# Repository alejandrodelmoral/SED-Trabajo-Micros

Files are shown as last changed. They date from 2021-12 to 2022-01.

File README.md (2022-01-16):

# Casa domótica 🏠

_Este proyecto se ha realizado para la asignatura de cuarto curso **Sistemas Electrónicos Digitales** impartida en el Grado en Ingeniería Electrónica Industrial y Automática, curso 2021/22._

**Escuela Técnica Superior de Ingeniería y Diseño Industrial**  
**Universidad Politécnica de Madrid**

## Miembros ✒️
* **Alejandro del Moral** - [alejandrodelmoral](https://github.com/alejandrodelmoral)
* **Jacob Sánchez** - [jacobsanchezmoreira](https://github.com/jacobsanchezmoreira)
* **Wei Zheng** - [weizheng13](https://github.com/weizheng13)

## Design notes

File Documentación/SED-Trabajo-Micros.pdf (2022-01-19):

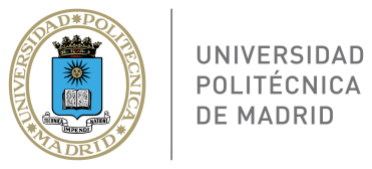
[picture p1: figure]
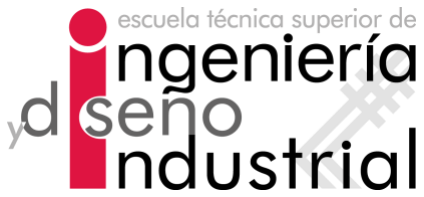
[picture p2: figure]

Alejandro del Moral Lapresta | 54753
Jacob Sánchez Moreira | 54863
Wei Zheng | 54911

## SISTEMAS ELECTRÓNICOS DIGITALES

## Universidad Politécnica de Madrid

Escuela Técnica Superior de Ingeniería y Diseño Industrial

Grado en Ingeniería Electrónica Industrial y Automática

# Casa domótica

Grupo: | Profesor:
A404 | Pedro Luis Castedo Cepeda

Madrid, enero de 2022

Sistemas Electrónicos Digitales | Casa domótica

### ÍNDICE DE CONTENIDOS

### ÍNDICE DE FIGURAS

### 1 INTRODUCCIÓN

En este proyecto se construirá y programará una casa domótica utilizando la placa de desarrollo STM32F407G-DISC1. Utilizando la tecnología se podrán realizar funciones para aumentar el grado de comodidad de las personas.

La casa constará de un control manual y un control por Bluetooth de la iluminación, temperatura, alarma y apertura de la puerta de la casa.

### 2 REALIZACIÓN DEL PROYECTO

### 2.1 COMPONENTES UTILIZADOS

a) Placa de desarrollo STM32F407G-DISC1
La placa utilizada posee un procesador Cortex-M4 de 32 bits RISC, de arquitectura Harvard con pipeline de 3 estados (Fech, decode y execute), lo que permite una ejecución eficiente del programa.

La documentación de la placa es muy extensa por lo que aquí se señalarán algunas de las características que han sido utilizadas para la realización de este trabajo.

- Frecuencia de reloj de hasta 168 MHz.
- Memoria Flash de 1 Mbyte.
- 3 conversores A/D de 12 bits.
- 2 conversores D/A de 12 bits.
- 12 temporizadores de 16 bits.
- 2 temporizadores de 32 bits.
- Hasta 140 puertos I/O con capacidad de interrupción.
- Comunicación I2C, USART, UART y CAN.

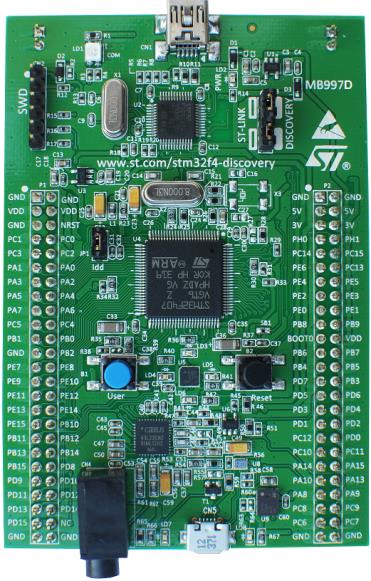
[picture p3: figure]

FIGURA 1. Placa STM32F407G b) Implementación del servomotor Datan S1213
De la hoja de características del fabricante podemos sacar los siguientes datos:
- Voltaje: 4,8 V
- Velocidad: 0,21 s / 60º
- Par: 6,5 kg ⋅ cm
- Peso: 46 g

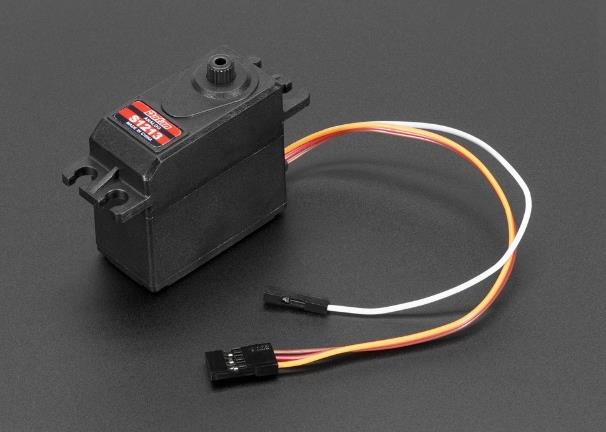
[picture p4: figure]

FIGURA 2. Servomotor Datan S1213

c) Implementación del módulo Bluetooth HC-06
Se ha decidido implementar una aplicación Bluetooth para poder elegir la función que se quiera ejecutar en la casa desde un dispositivo móvil.
- Protocolo Bluetooth: protocolo estándar Bluetooth V2.0
- Potencia: Class2 (+6 dBm)
- Banda: 2,40 HGz − 2,48 GHz, ISM Band
- Protocolo USB: USB v1.1/2.0
- Voltaje operativo: de +3,3 V a 6 V
- Rango de temperatura: de −20℃ a +55℃
- Intensidad operativa: 40 mA

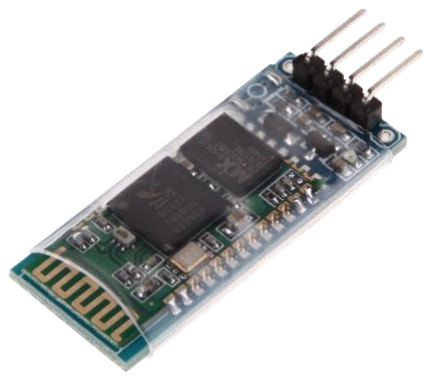
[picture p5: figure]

FIGURA 3. Módulo Bluetooth HC-06

d) Implementación del sensor de ultrasonidos HC-SR04
El sensor de ultrasonidos es un dispositivo electrónico usado para la detección de objetos y medición de distancias. Su funcionamiento se basa en el envío de ondas de alta frecuencia (40 kHz) que chocan con un objeto y se reflejan volviendo de nuevo al sensor.

En la hoja de especificaciones del fabricante nos encontramos con información detallada para el conexionado y parámetros característicos. Los datos más relevantes son los siguientes:

- Voltaje operativo: 5 V
- Intensidad operativa: 15 mA
- Frecuencia de trabajo máxima: 40 Hz
- Distancia de detección mínima: 2 cm
- Distancia de detección máxima: 400 cm
- Ángulo máximo de medición: 30º
- Pulso de señal de entrada (Trigger): 10 μs
- Pulso de señal de salida (Echo): Proporcional a la distancia, Máx de 23,3 ms

El envío de la señal ultrasónica es producido por el pin Trigger al ser excitado por un pulso de 10 μs. Es suficiente con la señal de 3,3 V que provee la placa para activarse.

La recepción de la señal es captada por el pin Echo, produciendo un pulso de duración idéntica al tiempo transcurrido entre el envío y la recepción de esa onda. Debido a que el voltaje de trabajo del sensor (5 V) y de la placa (3,3 V) son distintos, es necesario adaptar la amplitud de la señal a un rango que pueda leer la placa. Para ello se ha optado por implementar un divisor de tensión con dos resistencias (1 kΩ y 2 kΩ) para ajustar los valores de 5 a 3,3 V.

La distancia es fácilmente calculable sabiendo que la onda viaja a la velocidad del sonido, 340 m/s, y conociendo el ancho de pulso que nos proporciona el sensor. Sin embargo, el tiempo que nos proporciona el sensor es el transcurrido entre la ida y la vuelta, por lo que habría que dividir ese tiempo entre 2.

Distancia =

TiempoIda−Vuelta
2
- Vsonido

Para la obtención del tiempo a través de la lectura de la señal de salida del pin Echo se ha optado por el uso de un temporizador en modo de captura de señal. Este modo permite obtener el tiempo en el que se ha producido un flanco, ya sea de subida o de bajada.

La detección de los flancos es capturada con una interrupción del temporizador.

Sabiendo que se va a producir un pulso de duración determinada, es suficiente con detectar un flanco de subida, cambiar el modo de detección a flancos de bajada, y detectar un flanco de bajada. Con esa diferencia de tiempos se puede proceder al cálculo de la distancia.

No es un sensor muy preciso, se obtienen buenas aproximaciones de la distancia con errores de ± 0.5 cm. Suficiente para el propósito de nuestro trabajo.

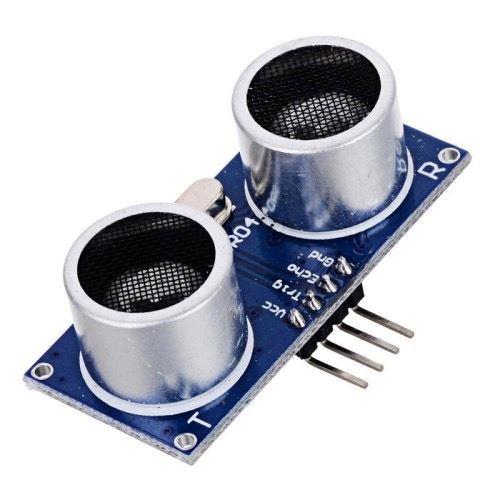
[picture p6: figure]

FIGURA 4. Sensor de ultrasonidos HC-SR04

e) Implementación del sensor LDR
Se trata de un resistor que varía su valor de resistencia eléctrica dependiendo de la cantidad de luz que incide sobre él.

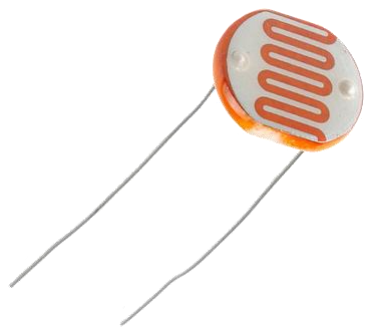
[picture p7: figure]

FIGURA 5. Sensor LDR

f) Implementación del zumbador pasivo
Se usa para generar un “chirrido” electromagnético utilizado para generar señales de sonido de diferentes frecuencias.

El principio de funcionamiento del zumbador pasivo es utilizar un pulso PWM que hace vibrar el aire para generar un sonido. Por ejemplo, enviando un pulso de 523 Hz, genera una nota Do, con 587 Hz un Re, y con 659 Hz un Mi.

Algunas de sus características son:

- Voltaje: de +3 V a 5 V
- Potencia: ≥ 85 dB
- Rango de frecuencia: de 50 Hz a 14 kHz
- Frecuencia de resonancia: ~2300 Hz
- Rango de temperatura: de −20℃ a 60℃
- Peso: 1,27 g

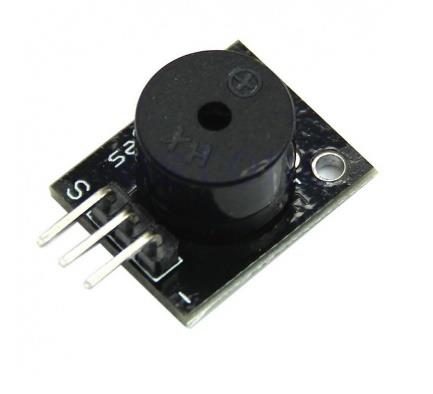
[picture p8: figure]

FIGURA 6. Zumbador pasivo

g) Implementación del sensor de temperatura
El sensor de temperatura externo consta de un termistor NTC, una resistencia dependiente de la temperatura.

El sensor posee dos salidas, una digital, ajustable mediante un potenciómetro que se activa una vez se ha superado cierto valor; y otra analógica, que provee el valor de la caída de potencial en la resistencia.

El circuito consta de un divisor de tensión compuesto por una resistencia fija de 10 kΩ y el termistor. La lectura será la diferencia de potencial entre el punto común de resistencia-termistor y tierra.

Debido a que el termistor no es lineal es necesario realizar ciertos cálculos para obtener el valor de la temperatura.

El voltaje medido será:

Vo =

RT
RT + R
- Vcc

Como el conversor que tiene el sensor es de 10 bits, el máximo valor que se leerá será de 1023. Por tanto, el valor leído del sensor será de:

ADC =

Vo

Vcc

- 1023

Sustituyendo en la primera ecuación se obtiene:

ADC =

RT
RT + R
- Vcc

Vcc

- 1023 =

RT
RT + R
- 1023

Despejando la incógnita del valor de la resistencia del termistor:

RT =

R
1023
ADC − 1

Se obtiene una aproximación de la temperatura a través de la fórmula del NTC.

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
Ln (

RT
R0

)

Por lo que, relacionando estas dos ecuaciones se llega a:

T = (
1
T0

+

1
B

Ln (
R · R0
1023
ADC − 1

))

−1

De la hoja de características que proporciona el fabricante del módulo se pueden obtener algunos de los valores necesarios para la obtención de la temperatura.

- T0 = 298.15 K (25ºC)
- B = 3950 K
- R0 = 10 kΩ
- R = 10 kΩ
- Rango de temperatura: -55ºC a 125ºC

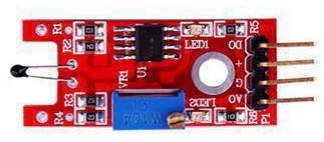
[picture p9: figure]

FIGURA 7. Sensor de temperatura

### 2.2 MONTAJE

Para la implementación de todo lo descrito anteriormente, se usará una placa de conexionado rápido (Protoboard).

Los pulsadores se han montado con una resistencia de 10 kΩ, de forma que sea una resistencia pulldown, es decir, que cuando se pulse el pulsador tendremos un valor alto de voltaje.

El sensor LDR también se ha armado con una resistencia de 1 kΩ para evitar dañar el componente, al igual que los leds.

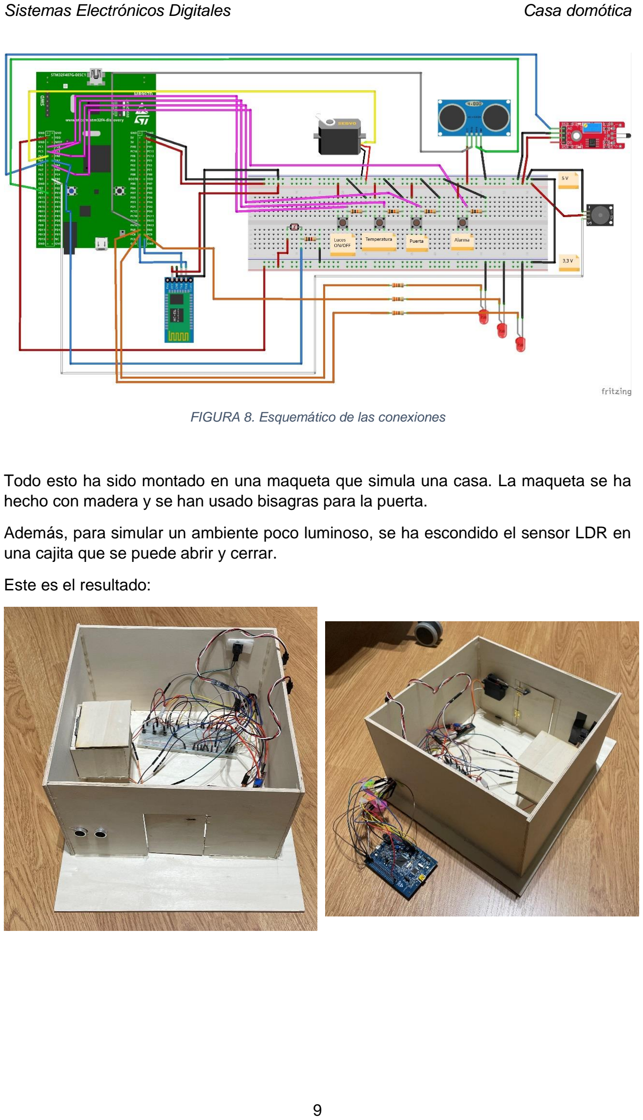
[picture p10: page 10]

FIGURA 8. Esquemático de las conexiones

Todo esto ha sido montado en una maqueta que simula una casa. La maqueta se ha hecho con madera y se han usado bisagras para la puerta.

Además, para simular un ambiente poco luminoso, se ha escondido el sensor LDR en una cajita que se puede abrir y cerrar.

Este es el resultado:

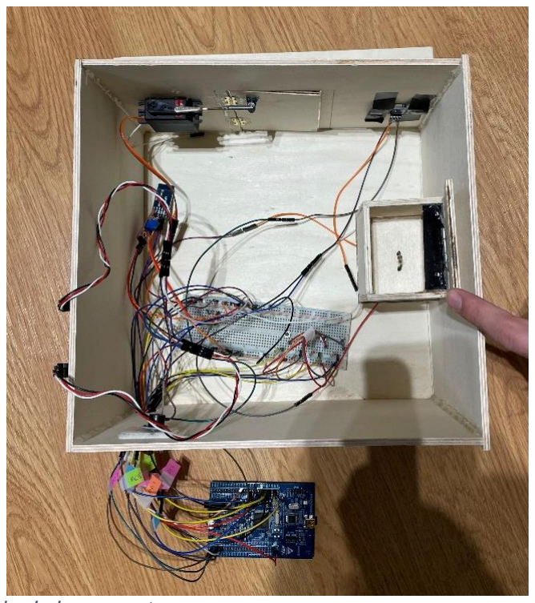
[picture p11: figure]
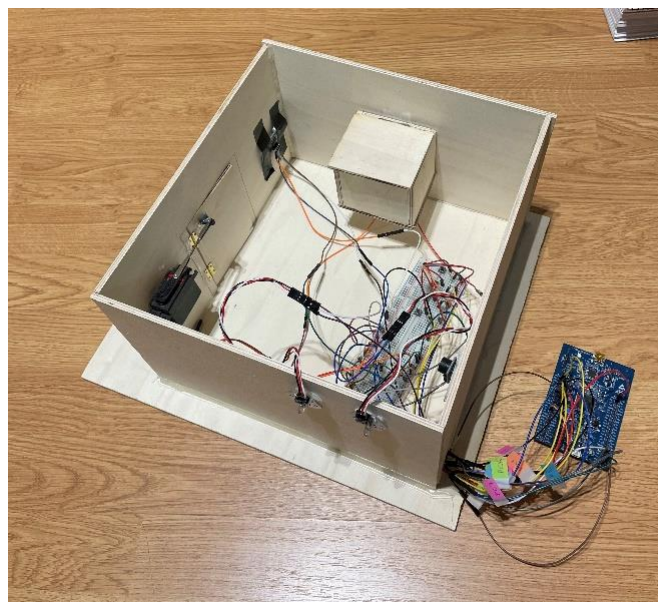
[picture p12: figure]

FIGURA 9. Montaje de la maqueta

### 2.3 FUNCIONAMIENTO

Las funciones que se han implementado en este proyecto son las siguientes:

a) Control de la iluminación
Se controlará un led a través del pin PC8 en función de la intensidad de luz que incida en la fotorresistencia (LDR). Es decir, si el valor que capta el sensor está por debajo de un cierto límite se encenderá el led, y si está por encima se apaga.

Además del sensor, se puede encender y apagar mediante un pulsador externo a la placa conectado al pin PC1 o mediante la aplicación móvil.

b) Control de la puerta
Esta funcionalidad permite abrir la puerta de entrada gracias al control de un servomotor, cuyo pin de señal se conecta al pin PA1.

Para abrir o cerrar, se usará un pulsador conectado al pin PC3 o mediante la aplicación móvil.

Una vez abierta la puerta, permanecerá en ese estado durante 5 s que, transcurrido ese tiempo, se cerrará automáticamente.

c) Control de la temperatura
Mediante la interacción de un pulsador conectado al pin PC2 o con la aplicación móvil, se puede medir la temperatura durante 10 s, que se mostrará por pantalla gracias al

Live Expressions del programa STM32CubeIDE. Transcurrido el tiempo, el sensor deja de medir.

Además, se encenderá un led conectado al pin PC9 que indica que se está midiendo.

d) Control de la alarma
Por último, se ha implementado una alarma (zumbador pasivo conectado al pin PB0) que suene cuando hay una distancia menor de 20 cm al sensor ultrasonidos.

El pin ECHO se conecta al pin PE9 y el TRIG al pin PA10.

La alarma se desconectará cuando pasen 5 s, se pulse un pulsador conectado al pin PA4 o se use la aplicación móvil.

También se encenderá un led conectado al pin PA8 cuando suene la alarma.

e) Aplicación móvil
La aplicación se ha desarrollado con la herramienta MIT App Inventor, una sencilla aplicación donde la programación se hace mediante bloques y la interfaz de forma gráfica, muy intuitiva.

Al pulsar un botón, el móvil envía un carácter mediante Bluetooth al módulo Bluetooth insertado en el proyecto (módulo HC-06).

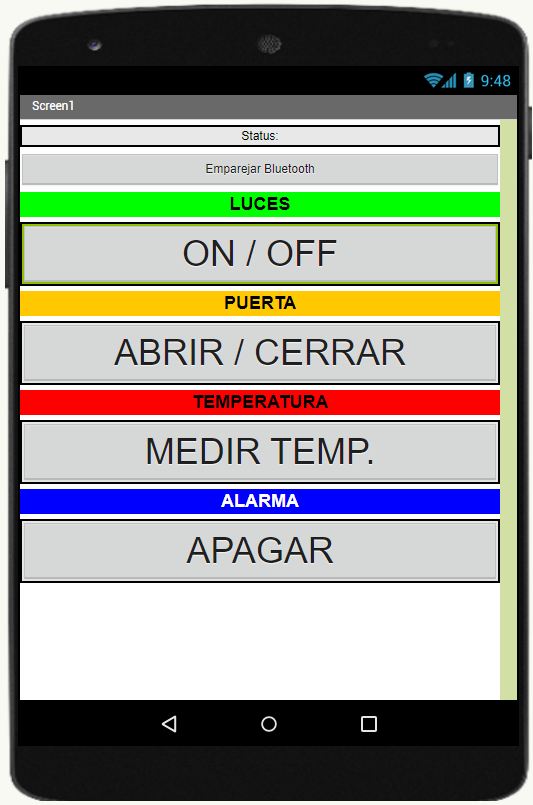
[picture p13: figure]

FIGURA 10. Captura de la aplicación móvil

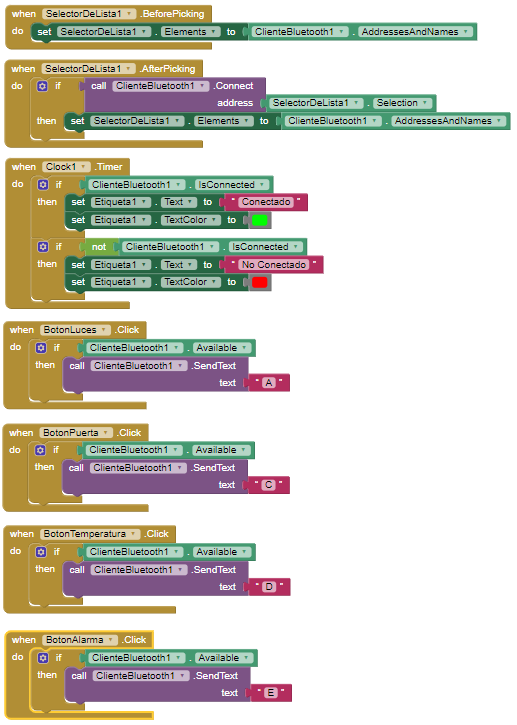
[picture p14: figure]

FIGURA 11. Programación de la aplicación móvil

### 3 MEJORAS Y PROBLEMAS

### 3.1 PROBLEMAS

Algunos de los problemas que han surgido durante el desarrollo del proyecto han sido:

1. Al querer poner tantos componentes, no hemos podido probarlos todos a la vez de primeras.
2. Lo que más problemas dio fue la programación de las funcionalidades del control de la iluminación, de la puerta y de la temperatura, debido a que tienen varios estados diferentes.
3. Al realizar la maqueta, hubo problemas con el servo que se montó inicialmente (el SG90) debido a que no era capaz de tirar de la puerta.
4. Los cables se desconectan fácilmente de los pines de la placa dificultando el correcto funcionamiento y la fluidez del mismo.
5. El módulo Bluetooth usado al principio no se emparejaba con ninguno de nuestros teléfonos móviles para poder usar la aplicación.

6. Al montar todo en la maqueta hemos utilizado muchos cables, lo que nos confundía bastante y nos ralentizaba a la hora de conectarlos en la placa.

### 3.2 SOLUCIONES A LOS PROBLEMAS ENCONTRADOS

Soluciones adoptadas a los problemas enunciados anteriormente:

1. Se ha necesitado ir probando componente a componente por separado, para entender su funcionamiento y saber utilizarlo.
2. Se solucionó a base de programar, probar y cambiar. Es lo que más tiempo ha llevado.
3. Se cambió al servo que usamos actualmente (el Datan S1213) ya que ofrece un par mayor, siendo capaz de tirar de la puerta con solvencia.
4. La única solución es tener precaución y estar revisando continuamente las conexiones.
5. Se tuvo que cambiar el módulo por otro que sí empareja correctamente.
6. Se han etiquetado todos los cables para acelerar el proceso de conexionado con la placa.

### 3.3 POSIBLES MEJORAS

Algunas mejoras que es posible implementar para mejorar el funcionamiento en el futuro:

- Sustituir algunos módulos de sensores por otros que tengan mayor precisión en las medidas, como es el caso del sensor de temperatura implementado con el termistor, únicamente tiene un conversor de 10 bits frente al de la placa de 12 bits. Aumentando el número de bits mejoraría la lectura de la temperatura.
- Añadir un módulo LCD que permita observar los valores de los sensores, simplificaría su uso, ya que para observar algunos valores como la temperatura hemos de acudir al Live Expressions del programa STM32CubeIDE.
- La placa utilizada siempre está conectada mediante un cable USB, esto produce cierta dependencia, ya que si no se dispone de ese conector no funcionaría. Una solución sería conectarlo a unas baterías.
- También se pueden plantear añadir más funcionalidades, como por ejemplo controlar persianas con un motor de continua, poner riego automático, etc.

### 4 ANEXO

### 4.1 ENLACE AL PROYECTO

A través del siguiente enlace se podrá acceder a todo el código desarrollado para el funcionamiento de este proyecto:

https://github.com/alejandrodelmoral/SED-Trabajo-Micros

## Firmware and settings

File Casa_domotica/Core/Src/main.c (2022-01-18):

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
/* Includes ------------------------------------------------------------------*/
#include "main.h"

/* USER CODE BEGIN Includes */

#include <math.h>

/* USER CODE END Includes */

ADC_HandleTypeDef hadc1;
ADC_HandleTypeDef hadc2;
ADC_HandleTypeDef hadc3;

TIM_HandleTypeDef htim1;
TIM_HandleTypeDef htim2;
TIM_HandleTypeDef htim3;

UART_HandleTypeDef huart6;

/* USER CODE BEGIN PV */

// Pulsadores
volatile int pulsador_luces_ON = 0;
volatile int pulsador_luces_OFF = 0;
volatile int pulsador_puerta = 0;
volatile int pulsador_temp = 0;
volatile int pulsador_alarma = 0;

// Bluetooth
char readBuf[1];

// Iluminación
int encendidas = 0;
int luces_ON = 0;
int luces_OFF = 0;
uint32_t LDR_valor;
uint32_t iluminacion;

// Puerta
int abierta = 0;
int abriendo = 0;
int cerrando = 0;
uint32_t puerta_temp;

// Temperatura
uint32_t Temp_valor;
float temp = 0;
float temperatura_medida;
int medida_temp = 0;
int midiendo_temp = 0;
int no_midiendo_temp = 0;
uint32_t temperatura_temp;

// Alarma
float dist  = 0;
int alarma_ON = 0;
uint8_t frec_zumb = 400;
uint32_t alarma_temp;

uint32_t IC_Val1 = 0;
uint32_t IC_Val2 = 0;
uint32_t Difference = 0;
uint8_t Is_First_Captured = 0;  // is the first value captured ?
uint8_t Distance  = 0;

// Detector de sonidos
uint32_t Sonidos_valor;

// Zumbador pasivo
uint8_t valor = 0;

/* USER CODE END PV */

void SystemClock_Config(void);
static void MX_GPIO_Init(void);
static void MX_USART6_UART_Init(void);
static void MX_TIM2_Init(void);
static void MX_ADC1_Init(void);
static void MX_ADC2_Init(void);
static void MX_TIM1_Init(void);
static void MX_ADC3_Init(void);
static void MX_TIM3_Init(void);
/* USER CODE BEGIN 0 */

// Bluetooth
void HAL_UART_RxCpltCallback(UART_HandleTypeDef *huart)
{
	if(huart->Instance == huart6.Instance)
		HAL_UART_Receive_IT(&huart6, (uint8_t*)readBuf, 1);
}

// Pulsadores
void HAL_GPIO_EXTI_Callback(uint16_t GPIO_Pin)
{
	if(GPIO_Pin == GPIO_PIN_0) { // Temperatura
		pulsador_temp = 1;
	}

	if(GPIO_Pin == GPIO_PIN_1) { // Iluminación
		pulsador_luces_ON = 1;
	}

	if(GPIO_Pin == GPIO_PIN_2) { // Temperatura
		pulsador_luces_OFF = 1;
	}

	if(GPIO_Pin == GPIO_PIN_3) { // Puerta
		pulsador_puerta = 1;
	}

	if(GPIO_Pin == GPIO_PIN_4) { // Alarma
		pulsador_alarma = 1;
	}
}

// Debouncer
int debouncer(volatile int* button_int, GPIO_TypeDef* GPIO_port, uint16_t GPIO_number)
{
	static uint8_t cuenta_boton = 0;
	static int cuenta = 0;

	if(*button_int == 1)
	{
		if(cuenta_boton == 0)
		{
			cuenta=HAL_GetTick();
			cuenta_boton++;
		}
		if(HAL_GetTick() - cuenta >= 20)
		{
			cuenta = HAL_GetTick();
			if(HAL_GPIO_ReadPin(GPIO_port, GPIO_number) != 1)
			{
				cuenta_boton = 1;
			}
			else
			{
				cuenta_boton++;
			}
			if(cuenta_boton == 2) // Periodo antirebotes
			{
				cuenta_boton = 0;
				*button_int = 0;
				return 1;
			}
		}
	}
	return 0;
}

// Servomotor
void moverServo(TIM_HandleTypeDef* htim, int grados)
{
	const int MAX = 20; // Max valor de frecuencia son 20ms -> 1/50Hz
	float ms = grados/90.0f + 0.5f; // De los valores min y max del servo (0.5ms son 0º, 2.5ms son 180º) -> Ecuacion recta
	float duty = ms/(float)MAX; // Porcentaje del ciclo encendido
	uint32_t CCR = htim->Instance->ARR * duty; // El valor del CCR es ARR * duty, el ARR es del propio htim
	htim->Instance->CCR2 = CCR; // Se asigna el CCR calculado al CCR2 del htim
}

// Ultrasonidos HC-SR04
float calcularDistancia(uint64_t time)
{
	const float Vsonido = 340.0f; // Velocidad sonido = 340m/s
	float dist = (float)time * Vsonido / 2.0f / 10000.0f; // El 1/10000 es por el cambio de conversion de s a us y de m a cm
	return dist; // En cm
}

void delay (uint16_t time)
{
	__HAL_TIM_SET_COUNTER(&htim1, 0);
	while (__HAL_TIM_GET_COUNTER (&htim1) < time);
}

void leerUltrasonido(void)
{
	HAL_GPIO_WritePin(GPIOA, GPIO_PIN_10, 1); // Activar TRIG
	delay(10); // Esperar 10 us = 0.01 ms
	HAL_GPIO_WritePin(GPIOA, GPIO_PIN_10, 0); // Desactivar TRIG
	__HAL_TIM_ENABLE_IT(&htim1, TIM_IT_CC1);
}

void HAL_TIM_IC_CaptureCallback(TIM_HandleTypeDef *htim)
{
	if (htim->Channel == HAL_TIM_ACTIVE_CHANNEL_1)  // if the interrupt source is channel1
	{
		if (Is_First_Captured==0) // if the first value is not captured
		{
			IC_Val1 = HAL_TIM_ReadCapturedValue(htim, TIM_CHANNEL_1); // read the first value
			Is_First_Captured = 1;  // set the first captured as true
			// Now change the polarity to falling edge
			__HAL_TIM_SET_CAPTUREPOLARITY(htim, TIM_CHANNEL_1, TIM_INPUTCHANNELPOLARITY_FALLING);
		}

		else if (Is_First_Captured==1)   // if the first is already captured
		{
			IC_Val2 = HAL_TIM_ReadCapturedValue(htim, TIM_CHANNEL_1);  // read second value
			__HAL_TIM_SET_COUNTER(htim, 0);  // reset the counter

			if (IC_Val2 > IC_Val1)
			{
				Difference = IC_Val2-IC_Val1;
			}

			else if (IC_Val1 > IC_Val2)
			{
				Difference = (0xffff - IC_Val1) + IC_Val2;
			}

			Distance = Difference * .034/2;
			//Distance = Difference;
			Is_First_Captured = 0; // set it back to false

			// set polarity to rising edge
			__HAL_TIM_SET_CAPTUREPOLARITY(htim, TIM_CHANNEL_1, TIM_INPUTCHANNELPOLARITY_RISING);
			__HAL_TIM_DISABLE_IT(&htim1, TIM_IT_CC1);
		}
	}
}

// Sensor de temperatura
float medirTemperatura(void)
{
	HAL_ADC_Start(&hadc2);
	if (HAL_ADC_PollForConversion(&hadc2, 100) == HAL_OK)
	{
		Temp_valor = HAL_ADC_GetValue(&hadc2);
	}
	HAL_ADC_Stop(&hadc2);

	uint32_t R_NTC = 10000.0 / (1023.0 / Temp_valor - 1.0);
	temp = 1.0 / ((1.0 / (25 + 273.15)) + (1.0 / 3950.0) * (log(R_NTC / 10000.0))) - 273.15;

	return temp;
}

// Sensor LDR
uint32_t medirLDR(void)
{
	HAL_ADC_Start(&hadc1);
	if(HAL_ADC_PollForConversion(&hadc1, 100) == HAL_OK) {
		LDR_valor = HAL_ADC_GetValue(&hadc1);
	}
	HAL_ADC_Stop(&hadc1);

	return LDR_valor;
}

// Control de la iluminación
void luces(void)
{
	iluminacion = medirLDR();

	if(encendidas == 0 && (iluminacion <= 50 || readBuf[0] == 'A' || debouncer(&pulsador_luces_ON, GPIOC, GPIO_PIN_1) == 1)) // Si hay poca luminosidad, o si se usa Bluetooth o si se pulsa el botón
	{
		luces_ON = 1; // Activación del flag para encender

		readBuf[0] = 0; // Reinicio del Bluetooth
		pulsador_luces_ON = 0; // Reinicio del pulsador
	}

	if(encendidas == 1 && (iluminacion > 90 || readBuf[0] == 'A' || debouncer(&pulsador_luces_ON, GPIOC, GPIO_PIN_1) == 1)) // Si hay suficiente luminosidad, o si se usa Bluetooth o si se pulsa el botón
	{
		luces_OFF = 1; // Activación del flag para apagar

		readBuf[0] = 0; // Reinicio del Bluetooth
		pulsador_luces_ON = 0; // Reinicio del pulsador
	}

	if(encendidas == 0 && luces_ON == 1) // Si están apagadas y activado el flag para encender, se encienden
	{
		encendidas = 1; // Encendidas
		luces_ON = 0; // Desactivación del flag para encender
	}

	if(encendidas == 1 && luces_OFF == 1) // Si están encendidas y activado el flag para apagar, se apagan
	{
		encendidas = 0; // Apagadas
		luces_OFF = 0; // Desactivación del flag para apagar
	}

	HAL_GPIO_WritePin(GPIOC, GPIO_PIN_8, encendidas); // LED encendido cuando se encienden las luces
}

// Control de la puerta
void puerta(void)
{
	if(readBuf[0] == 'C' || debouncer(&pulsador_puerta, GPIOC, GPIO_PIN_3)) // Si se usa Bluetooth o si se pulsa el botón
	{
		 if(abierta == 0) // Si la puerta está cerrada
		 {
			 abriendo = 1; // Activación del flag para abrir puerta
		 }

		 else // Si la puerta está abierta
		 {
			 cerrando = 1; // Activación del flag para cerrar puerta
			 puerta_temp = 0; // Reinicio del tiempo de la puerta abierta
		 }

		 readBuf[0] = 0; // Reinicio del Bluetooth
		 pulsador_puerta = 0; // Reinicio del pulsador
	}

	if(abierta == 0 && abriendo == 1) // Si la puerta está cerrada y activado el flag para abrir la puerta, se abre
	{
		moverServo(&htim2, 90); // Se abre la puerta
		abierta = 1; // Puerta ya abierta
		abriendo = 0; // Desactivación del flag para abrir puerta
		puerta_temp = HAL_GetTick(); // Se coge el tiempo actual
	}

	if(abierta == 1 && cerrando == 0 && (HAL_GetTick() - puerta_temp) > 5000) // Si la puerta está abierta, desactivado el flag para cerrar la puerta y han pasado 5s, se cierra
	{
		cerrando = 1; // Activación del flag para cerrar puerta
		puerta_temp = 0; // Reinicio del tiempo de la puerta abierta
	}

	if(abierta == 1 && cerrando == 1) // Si la puerta está abierta y activado el flag para cerrar la puerta, se cierra
	{
		moverServo(&htim2, 0); // Se cierra la puerta
		abierta = 0; // Puerta ya cerrada
		cerrando = 0; // Desactivación del flag para cerrar puerta
		puerta_temp = 0; // Reinicio del tiempo de la puerta abierta
	}
}

// Control de la temperatura
void temperatura(void)
{
	if(readBuf[0] == 'D' || debouncer(&pulsador_luces_OFF, GPIOC, GPIO_PIN_2) == 1) // Si se usa Bluetooth o si se pulsa el botón
	{
		 if(medida_temp == 0) // Si no se está midiendo
		 {
			 midiendo_temp = 1; // Activación del flag para medir
		 }

		 else // Si se está midiendo
		 {
			 no_midiendo_temp = 1; // Activación del flag para no medir
			 temperatura_temp = 0; // Reinicio del tiempo de la medición
		 }

		 readBuf[0] = 0; // Reinicio del Bluetooth
		 pulsador_temp = 0; // Reinicio del pulsador
	}

	if(medida_temp == 0 && midiendo_temp == 1) // Si no se está midiendo y activado el flag para medir, se mide
	{
		temperatura_medida = medirTemperatura(); // Se mide la temperatura

		medida_temp = 1; // Midiendo
		midiendo_temp = 0; // Desactivación del flag para medir
		temperatura_temp = HAL_GetTick(); // Se coge el tiempo actual
	}

	if(medida_temp == 1 && no_midiendo_temp == 0 && (HAL_GetTick() - temperatura_temp) > 10000) // Si está midiendo, desactivado el flag para no medir y han pasado 10s, no mide
	{
		no_midiendo_temp = 1; // Activación del flag para no medir
		temperatura_temp = 0; // Reinicio del tiempo de la medición
	}

	if(medida_temp == 1 && no_midiendo_temp == 1) // Si está midiendo y activado el flag para no medir, no mide
	{
		medida_temp = 0; // No midiendo
		no_midiendo_temp = 0; // Desactivación del flag para no medir
		temperatura_temp = 0; // Reinicio del tiempo de la medición
		temperatura_medida = 0;
	}

	HAL_GPIO_WritePin(GPIOC, GPIO_PIN_9, medida_temp); // LED encendido cuando se mide temperatura
}

// Control de la alarma
void alarma(void)
{
	leerUltrasonido(); // Leer Ultrasonido conectado a pin A10
	HAL_Delay(100); // Espera para volver a disparar, NO menor a 100ms !!!

	if(Distance < 20) // Si la distancia al sensor es menor de 10cm
	{
		alarma_ON = 1; // Activación de la alarma
		alarma_temp = HAL_GetTick(); // Se coge el tiempo actual
		htim3.Instance->CCR3 = frec_zumb; // Se enciende la alarma
	}

	if(alarma_ON == 1) // Si está activada la alarma
	{
		if(readBuf[0] == 'E' || debouncer(&pulsador_alarma, GPIOA, GPIO_PIN_4) || HAL_GetTick() - alarma_temp > 5000) // Si se usa Bluetooth, o si se pulsa el botón o han pasado 5s, se desactiva
		{
			alarma_ON = 0; // Desactivación de la alarma
			htim3.Instance->CCR3 = 0; // Se apaga la alarma
			alarma_temp = 0; // Reinicio del tiempo de la alarma
			readBuf[0] = 0; // Reinicio del Bluetooth
			pulsador_alarma = 0; // Reinicio del pulsador
		}
	}

	HAL_GPIO_WritePin(GPIOA, GPIO_PIN_8, alarma_ON); // LED encendido cuando suena la alarma
}

/* USER CODE END 0 */

/**
  * @brief  The application entry point.
  * @retval int
  */
int main(void)
{
  /* MCU Configuration--------------------------------------------------------*/

  /* Reset of all peripherals, Initializes the Flash interface and the Systick. */
  HAL_Init();

  /* Configure the system clock */
  SystemClock_Config();

  /* Initialize all configured peripherals */
  MX_GPIO_Init();
  MX_USART6_UART_Init();
  MX_TIM2_Init();
  MX_ADC1_Init();
  MX_ADC2_Init();
  MX_TIM1_Init();
  MX_ADC3_Init();
  MX_TIM3_Init();
  /* USER CODE BEGIN 2 */

  HAL_UART_Receive_IT(&huart6, (uint8_t*)readBuf, 1);
  HAL_TIM_IC_Start_IT(&htim1, TIM_CHANNEL_1);
  HAL_TIM_PWM_Start(&htim2, TIM_CHANNEL_2);
  HAL_TIM_PWM_Start(&htim3, TIM_CHANNEL_3);

  /* USER CODE END 2 */

  /* Infinite loop */
  /* USER CODE BEGIN WHILE */
  while (1)
  {
    /* USER CODE END WHILE */

    /* USER CODE BEGIN 3 */

	  puerta(); // Control puerta
	  luces(); // Control iluminación
	  temperatura(); // Control temperatura
	  alarma(); // Control alarma

  }
  /* USER CODE END 3 */
}

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


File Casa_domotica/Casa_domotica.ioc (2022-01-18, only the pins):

Mcu.UserName=STM32F407VGTx
PA0-WKUP.Signal=GPXTI0
PA1.GPIO_Label=Servo
PA1.Signal=S_TIM2_CH2
PA10.GPIO_Label=TRIG
PA10.Signal=GPIO_Output
PA2.GPIO_Label=LDR
PA2.Signal=ADCx_IN2
PA3.GPIO_Label=Temperatura
PA3.Signal=ADCx_IN3
PA4.GPIO_Label=Pulsador alarma
PA4.Signal=GPXTI4
PA8.GPIO_Label=LED alarma
PA8.Signal=GPIO_Output
PB0.GPIO_Label=Zumbador pasivo
PB0.Signal=S_TIM3_CH3
PC0.GPIO_Label=Detector de sonidos
PC0.Signal=ADCx_IN10
PC1.GPIO_Label=Pulsador luces ON
PC1.Signal=GPXTI1
PC14-OSC32_IN.Signal=RCC_OSC32_IN
PC15-OSC32_OUT.Signal=RCC_OSC32_OUT
PC2.GPIO_Label=Pulsador luces OFF
PC2.Signal=GPXTI2
PC3.GPIO_Label=Pulsador puerta
PC3.Signal=GPXTI3
PC6.Signal=USART6_TX
PC7.Signal=USART6_RX
PC8.GPIO_Label=LED iluminaci\u00F3n
PC8.Signal=GPIO_Output
PC9.GPIO_Label=LED temperatura
PC9.Signal=GPIO_Output
PD12.Signal=GPIO_Output
PE9.GPIO_Label=ECHO
PE9.Signal=S_TIM1_CH1
PH0-OSC_IN.Signal=RCC_OSC_IN
PH1-OSC_OUT.Signal=RCC_OSC_OUT

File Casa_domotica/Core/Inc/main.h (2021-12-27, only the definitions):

#define Detector_de_sonidos_Pin GPIO_PIN_0
#define Detector_de_sonidos_GPIO_Port GPIOC
#define Pulsador_luces_ON_Pin GPIO_PIN_1
#define Pulsador_luces_ON_GPIO_Port GPIOC
#define Pulsador_luces_ON_EXTI_IRQn EXTI1_IRQn
#define Pulsador_luces_OFF_Pin GPIO_PIN_2
#define Pulsador_luces_OFF_GPIO_Port GPIOC
#define Pulsador_luces_OFF_EXTI_IRQn EXTI2_IRQn
#define Pulsador_puerta_Pin GPIO_PIN_3
#define Pulsador_puerta_GPIO_Port GPIOC
#define Pulsador_puerta_EXTI_IRQn EXTI3_IRQn
#define Servo_Pin GPIO_PIN_1
#define Servo_GPIO_Port GPIOA
#define LDR_Pin GPIO_PIN_2
#define LDR_GPIO_Port GPIOA
#define Temperatura_Pin GPIO_PIN_3
#define Temperatura_GPIO_Port GPIOA
#define Pulsador_alarma_Pin GPIO_PIN_4
#define Pulsador_alarma_GPIO_Port GPIOA
#define Pulsador_alarma_EXTI_IRQn EXTI4_IRQn
#define Zumbador_pasivo_Pin GPIO_PIN_0
#define Zumbador_pasivo_GPIO_Port GPIOB
#define ECHO_Pin GPIO_PIN_9
#define ECHO_GPIO_Port GPIOE
#define LED_iluminaci_n_Pin GPIO_PIN_8
#define LED_iluminaci_n_GPIO_Port GPIOC
#define LED_temperatura_Pin GPIO_PIN_9
#define LED_temperatura_GPIO_Port GPIOC
#define LED_alarma_Pin GPIO_PIN_8
#define LED_alarma_GPIO_Port GPIOA
#define TRIG_Pin GPIO_PIN_10
#define TRIG_GPIO_Port GPIOA

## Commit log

2021-12-02 Actualización de README.md
2021-12-09 Modificado para la placa STM323F407
2021-12-10 Prueba moviendo servo
2021-12-10 Implementada funcion moverServo
    Funcion que permite mover un servo X grados
2021-12-11 Prueba sensor LDR
2021-12-18 Creado esqumático
    [Schematic.fzz]
2021-12-18 Sensor de temperatura
2021-12-18 Sensor detector de sonidos
2021-12-20 Implementado servo en el código principal
2021-12-20 Implementad LDR en el proyecto principal
2021-12-20 Implementado sensor de temperatura en el proyecto principal
2021-12-20 Implementado ultrasonidos en el proyecto principal
2021-12-20 Implementado detector de sonidos en proyecto principal
2021-12-20 Implementado zumbador pasivo en el proyecto principal
2021-12-22 Creada la función para encender la luz
2021-12-22 Empezando el control de la puerta
2021-12-26 Control de la puerta terminado
2021-12-26 Algunos cambios
    [Schematic.fzz]
2021-12-26 Control de temperatura implementado
    [Schematic.fzz]
2021-12-26 Nueva función para temperatura
2021-12-27 Control de la alarma implementado
2021-12-27 Mejorando el código
2021-12-27 Avanzando el esquemático
    [Schematic.fzz]
2021-12-27 Prueba en el servo
2021-12-29 Mejora esquemático
    [Schematic.fzz]
2021-12-30 Implementado el control de la iluminación
2022-01-16 Limpiando GitHub
    [Schematic.fzz]
2022-01-16 Esquemático final
    [Schematic.fzz]

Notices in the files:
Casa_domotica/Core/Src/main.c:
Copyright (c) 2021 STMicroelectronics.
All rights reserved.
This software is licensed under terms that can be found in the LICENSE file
